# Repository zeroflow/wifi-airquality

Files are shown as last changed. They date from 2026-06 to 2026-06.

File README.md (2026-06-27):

# wifi-airquality

Air-quality monitor with a visual air-quality indicator, built with
[ESPHome](https://esphome.io/) and [Home Assistant](https://www.home-assistant.io/).
Companion project to a fan controller: when the basement air gets dirty, the
lightbar shows it and the fans throttle down or switch off.

*Sponsored by [Seeed Studio](https://www.seeedstudio.com/).*

## Devices

| Config | MCU | Hardware |
| --- | --- | --- |
| [`sensor.yaml`](sensor.yaml) | Seeed XIAO ESP32-C6 | Sensirion SEN55 (PM/VOC/NOx/T/RH) + SHT41, OLED, RTC, buzzer |
| [`ledbar.yaml`](ledbar.yaml) | Seeed XIAO ESP32-C3 | 10-LED WS2812 lightbar as an AQI gauge |

The **sensor** station measures particulate matter, VOC, NOx, temperature and
humidity and publishes them to Home Assistant. The **lightbar** subscribes to a
Home Assistant air-quality score and visualizes it (green = good, breathing red
= warning, blinking red = critical), with configurable thresholds and brightness.

## Package Library

This repository is an ESPHome **package library** — composable building blocks you import
directly into your own device config via `packages: github://`. No forking required.

All packages are tagged at `@v1.0.0`. Use this tag in production configs for stability.
See each layer's `README.md` for full documentation, exposed ids, and `!extend` examples.

### Hardware layer — [`packages/hardware/`](packages/hardware/)

| Package | One-liner | Import key |
|---|---|---|
| `xiao-esp32c3.yaml` | Seeed XIAO ESP32-C3 MCU + ESP-IDF framework | `mcu` |
| `xiao-esp32c6.yaml` | Seeed XIAO ESP32-C6 MCU + ESP-IDF framework | `mcu` |
| `grove-expansion-base.yaml` | XIAO Expansion Base — I2C, OLED, RTC, buzzer, button | `shield` |
| `grove-led-driver.yaml` | Grove LED Driver Board — 10-LED WS2812 strip on GPIO07 | `led_hw` |

### Sensors layer — [`packages/sensors/`](packages/sensors/)

| Package | One-liner | Import key |
|---|---|---|
| `sen55.yaml` | Sensirion SEN55 — PM1/2.5/4/10 + VOC + NOx + T/RH | `sensors_sen` |
| `sht41.yaml` | Sensirion SHT41 — temperature + humidity | `sensors_sht` |

### Display layer — [`packages/display/`](packages/display/)

| Package | One-liner | Import key |
|---|---|---|
| `oled-airquality.yaml` | Air-quality dashboard on the OLED (T/RH, PM, VOC/NOx, bar) | `oled_display` |

### AQI gauge layer — [`packages/aqi/`](packages/aqi/)

| Package | One-liner | Import key |
|---|---|---|
| `ledbar-gauge.yaml` | AQI Gauge effect on LED strip — 4-state visual from HA sensor | `aqi_gauge` |

---

### Copy-paste import snippets

**Sensor station** (XIAO C6 + Expansion Base + SEN55 + SHT41 + OLED):

```yaml
# Shorthand — no substitution overrides needed
packages:
  mcu:          github://zeroflow/wifi-airquality/packages/hardware/xiao-esp32c6.yaml@v1.0.0
  shield:       github://zeroflow/wifi-airquality/packages/hardware/grove-expansion-base.yaml@v1.0.0
  sensors_sen:  github://zeroflow/wifi-airquality/packages/sensors/sen55.yaml@v1.0.0
  sensors_sht:  github://zeroflow/wifi-airquality/packages/sensors/sht41.yaml@v1.0.0
  oled_display: github://zeroflow/wifi-airquality/packages/display/oled-airquality.yaml@v1.0.0
```

**LED bar gauge** (XIAO C3 + LED Driver + AQI Gauge):

```yaml
# Shorthand — uses default HA entity sensor.air_quality_score
packages:
  mcu:       github://zeroflow/wifi-airquality/packages/hardware/xiao-esp32c3.yaml@v1.0.0
  led_hw:    github://zeroflow/wifi-airquality/packages/hardware/grove-led-driver.yaml@v1.0.0
  aqi_gauge: github://zeroflow/wifi-airquality/packages/aqi/ledbar-gauge.yaml@v1.0.0
```

**LED bar gauge with custom HA entity** (long-form with `vars:`):

```yaml
# Long-form — override aqi_entity_id to match your Home Assistant entity name
packages:
  mcu:    github://zeroflow/wifi-airquality/packages/hardware/xiao-esp32c3.yaml@v1.0.0
  led_hw: github://zeroflow/wifi-airquality/packages/hardware/grove-led-driver.yaml@v1.0.0
  aqi_gauge:
    url: github://zeroflow/wifi-airquality/packages/aqi/ledbar-gauge.yaml@v1.0.0
    vars:
      aqi_entity_id: sensor.basement_air_quality
```

**Custom LED strip** (long-form overriding `led_count` and `led_pin`):

```yaml
packages:
  led_hw:
    url: github://zeroflow/wifi-airquality/packages/hardware/grove-led-driver.yaml@v1.0.0
    vars:
      led_count: "30"
      led_pin: GPIO04
```

**Custom SEN55 poll rate** (long-form overriding `sen55_update_interval`):

```yaml
packages:
  sensors_sen:
    url: github://zeroflow/wifi-airquality/packages/sensors/sen55.yaml@v1.0.0
    vars:
      sen55_update_interval: "10s"
```

---

## Enclosures

3D-printable mounts for both devices live in [`enclosure/`](enclosure/).

## Setup

Secrets are kept out of git. Create a `secrets.yaml` next to the configs:

```yaml
wifi_ssid: "your-ssid"
wifi_password: "your-password"
```

## Build

Validate and flash with ESPHome:

```bash
esphome config sensor.yaml
esphome run sensor.yaml
esphome run ledbar.yaml
```

## License

[MIT](LICENSE)

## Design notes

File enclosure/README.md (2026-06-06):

# Enclosures

Minimal 3D-printable mounts for the two devices. The goal is simply to keep the
PCBs from lying around loose and to hold the stack together. They are not meant to
be pretty or sturdy, just simple. Each `.3mf` is print-ready, and the `.png` next
to it is a render of the assembled result.

| Device | Model | Render |
| --- | --- | --- |
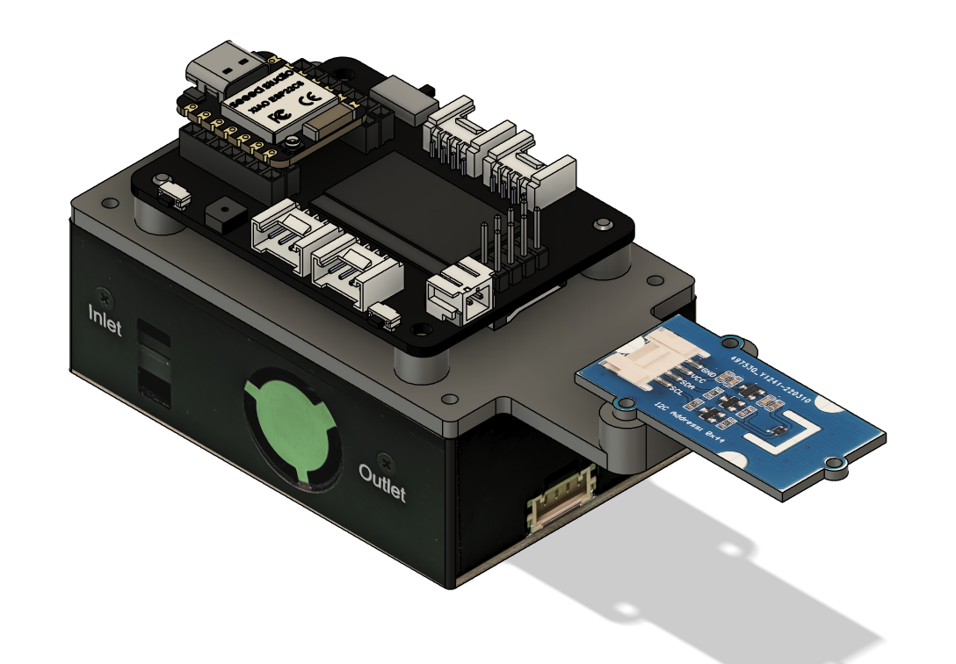
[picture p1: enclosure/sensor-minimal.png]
sensor
| [`sensor`](../sensor.yaml) | [`sensor-minimal.3mf`](sensor-minimal.3mf) |  |
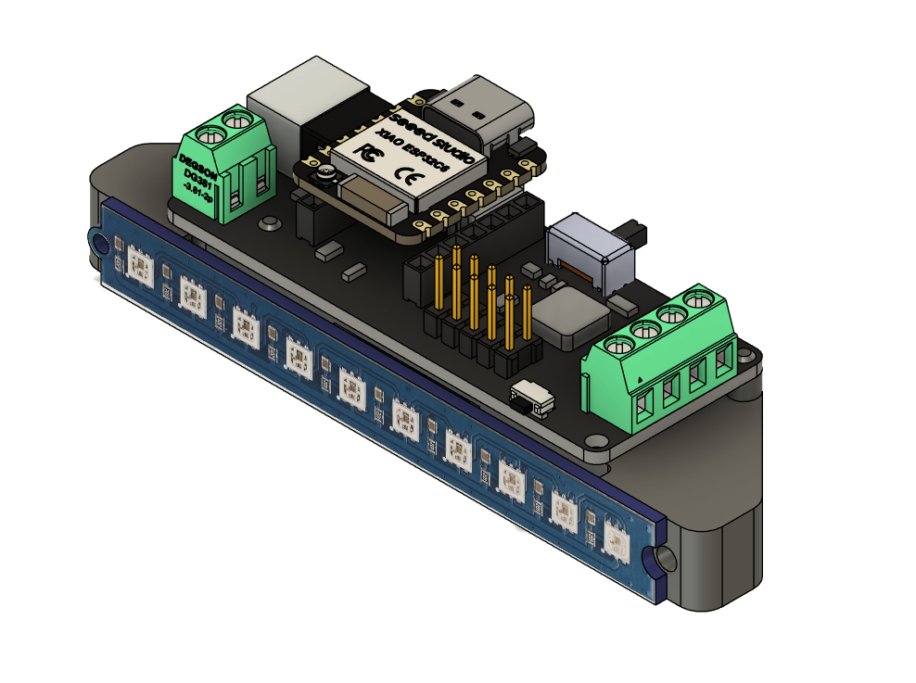
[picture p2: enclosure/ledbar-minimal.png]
ledbar
| [`ledbar`](../ledbar.yaml) | [`ledbar-minimal.3mf`](ledbar-minimal.3mf) |  |

## sensor

Replaces the SEN55's top plate: the printed part drops straight onto the sensor
in place of the stock cover. It carries the rest of the stack on top.

- **XIAO distribution board**, mounted with **M3** screws.
- **SHT41** breakout, mounted with **M2** screws.

## ledbar

A flat carrier for the lightbar and its XIAO.

- **LED strip**, glued and screwed down (**M3 + M2**).
- **XIAO board**, held by double-sided tape only, no screws.

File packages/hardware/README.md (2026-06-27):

# packages/hardware/

Hardware packages for the Seeed XIAO series and Grove peripherals. Each package
configures the MCU or a Grove board and exposes stable `id`s for composition.

---

## `xiao-esp32c3.yaml`

**What it configures:** Seeed XIAO ESP32-C3 MCU and ESP-IDF framework — nothing else.

**Hardware / package dependencies:**
- None (board-only package; no Grove peripherals)

**Exposed ids:**

*(No ids exposed — MCU and framework declaration only)*

**Substitutions:**

| name | value | purpose |
|---|---|---|
| `pin_a0` | `"2"` | A0 silkscreen → GPIO2 |
| `pin_d3` | `"5"` | D3 silkscreen → GPIO5 |
| `pin_d4` | `"6"` | D4 / SDA → GPIO6 |
| `pin_d5` | `"7"` | D5 / SCL → GPIO7 (== legacy MVP GPIO07) |

These substitutions are a **workaround** for missing XIAO C3 silkscreen aliases in ESPHome
2026.5.0 (pinned). ESPHome PR #17002 adds C3/S3 aliases but targets the unreleased 2026.6.0.
Feature packages (e.g. `grove-led-driver-i2c.yaml`) reference `${pin_a0}` / `${pin_d5}` /
`${pin_d3}` directly at point of use — no nested substitution-in-substitution indirection.

**Example override with `!extend`:**

The XIAO C3 package has no exposed ids, so `!extend` is not applicable.
Consumer adds device identity, networking, and peripherals in their own config.

**Import:**

```yaml
packages:
  mcu: github://zeroflow/wifi-airquality/packages/hardware/xiao-esp32c3.yaml@v1.0.0
  # local development:
  # mcu: !include packages/hardware/xiao-esp32c3.yaml
```

---

## `xiao-esp32c6.yaml`

**What it configures:** Seeed XIAO ESP32-C6 MCU and ESP-IDF framework — nothing else.

**Hardware / package dependencies:**
- None (board-only package; no Grove peripherals)

**Exposed ids:**

*(No ids exposed — MCU and framework declaration only)*

**Substitutions:**

| name | value | purpose |
|---|---|---|
| `pin_a0` | `"0"` | A0 silkscreen → GPIO0 |
| `pin_d3` | `"21"` | D3 silkscreen → GPIO21 |
| `pin_d4` | `"22"` | D4 / SDA → GPIO22 |
| `pin_d5` | `"23"` | D5 / SCL → GPIO23 |

See C3 note above — same workaround applies for the C6 pin-name substitutions.

**Example override with `!extend`:**

The XIAO C6 package has no exposed ids, so `!extend` is not applicable.
Consumer adds device identity, networking, and peripherals in their own config.

**Import:**

```yaml
packages:
  mcu: github://zeroflow/wifi-airquality/packages/hardware/xiao-esp32c6.yaml@v1.0.0
  # local development:
  # mcu: !include packages/hardware/xiao-esp32c6.yaml
```

---

## `grove-expansion-base.yaml`

**What it configures:** All onboard peripherals of the Seeed XIAO Expansion Base — I2C bus,
0.96" OLED (shows clock by default), PCF8563 RTC with SNTP write-back, passive buzzer,
and user button.

**Hardware / package dependencies:**
- Requires a XIAO board package (`xiao-esp32c3.yaml` or `xiao-esp32c6.yaml`) for the
  underlying MCU

**Exposed ids:**

| id | type | notes |
|----|---|---|
| `bus_a` | i2c | SDA=D4, SCL=D5 (overridable via substitutions); consumed by sensor and display packages |
| `oled` | display (ssd1306\_i2c 0x3C) | 128×64 OLED; default lambda shows clock; `!extend` target for custom display content |
| `roboto` | font (Roboto, size 14) | Referenced in display lambdas |
| `rtc_time` | time (pcf8563 0x51) | Hardware RTC; SNTP writes back to it on sync |
| `sntp_time` | time (sntp) | SNTP source; writes to `rtc_time` on sync |
| `user_button` | binary\_sensor (gpio D1, pullup, inverted) | Bare GPIO — no automations in package |
| `buzzer_out` | output (ledc D3) | LEDC PWM output driving the buzzer |
| `buzzer` | rtttl | RTTTL player; play tones via `rtttl.play` |

**Substitutions:**

| name | default | purpose |
|---|---|---|
| `i2c_sda` | `D4` | I2C SDA pin |
| `i2c_scl` | `D5` | I2C SCL pin |

**Example override with `!extend`:**

```yaml
# Change the OLED content without forking the package
display:
  - id: !extend oled
    lambda: |-
      it.printf(0, 0, id(roboto), "PM2.5: %.0f", id(sen_pm25).state);
```

**Import:**

```yaml
packages:
  shield: github://zeroflow/wifi-airquality/packages/hardware/grove-expansion-base.yaml@v1.0.0
  # local development:
  # shield: !include packages/hardware/grove-expansion-base.yaml
```

---

## `grove-led-driver-i2c.yaml`

**What it configures:** Seeed LED Driver Board for XIAO — **I2C variant**.

- `aqi_strip` — WS2812 addressable LED strip on the terminal-block LED connector (A0 / `${pin_a0}`)
- `driver_button` — user button on D3 / `${pin_d3}` (INPUT_PULLUP, inverted, no automations)

The Grove I2C connector is **left free** for the consumer. Pair with `grove-expansion-base.yaml`
or add your own `i2c:` block to use I2C sensors/OLED on that connector.

Consumers add effects via `!extend aqi_strip`. See `packages/aqi/ledbar-gauge.yaml` for an
AQI gauge effect that extends this strip.

**Hardware / package dependencies:**
- Requires a XIAO board package (`xiao-esp32c3.yaml` or `xiao-esp32c6.yaml`) — the board
  package exports `pin_a0` and `pin_d3` consumed here

**Exposed ids:**

| id | type | notes |
|----|---|---|
| `aqi_strip` | light (esp32\_rmt\_led\_strip) | 10 LEDs, WS2812, GRB order; `!extend` target for effect packages |
| `driver_button` | binary\_sensor (gpio INPUT\_PULLUP inverted) | Bare GPIO on D3 — no automations in package |

**Substitutions:**

| name | default | purpose |
|---|---|---|
| `led_count` | `"10"` | Number of LEDs in the strip |

Pins (`pin_a0`, `pin_d3`) are exported by the board package — override them at the board level,
not here. Do not nest `${pin_a0}` inside another substitution value.

**Pin map:**

| Silkscreen | C3 GPIO | C6 GPIO | Connected to |
|---|---|---|---|
| A0 | GPIO2 | GPIO0 | Terminal-block LED strip data (`aqi_strip`) |
| D3 | GPIO5 | GPIO21 | User button (`driver_button`) |

Note: The GPIO numbers are provided by the board package substitutions as a workaround for
missing C3 silkscreen aliases in ESPHome 2026.5.0 (PR #17002 not yet released).

**Example override with `!extend`:**

```yaml
# Add a Rainbow effect to the strip without forking the package
light:
  - id: !extend aqi_strip
    effects:
      - random:
          name: "Twinkle"
          transition_length: 600ms
          update_interval: 300ms
```

**Import:**

```yaml
packages:
  mcu:    github://zeroflow/wifi-airquality/packages/hardware/xiao-esp32c3.yaml@v1.0.0
  led_hw: github://zeroflow/wifi-airquality/packages/hardware/grove-led-driver-i2c.yaml@v1.0.0
  # local development:
  # led_hw: !include packages/hardware/grove-led-driver-i2c.yaml
```

---

## `grove-led-driver-neopixel.yaml`

**What it configures:** Seeed LED Driver Board for XIAO — **Neopixel variant**.

- `aqi_strip` — WS2812 addressable LED strip on the terminal-block LED connector (A0 / `${pin_a0}`)
- `grove_strip` — second WS2812 strip on the Grove I2C connector repurposed as D5 / `${pin_d5}` data output
- `driver_button` — user button on D3 / `${pin_d3}` (INPUT_PULLUP, inverted, no automations)

The Grove I2C connector is **repurposed** as a neopixel data line in this variant.
The Grove connector is **NOT available for I2C** here. Use the I2C variant
(`grove-led-driver-i2c.yaml`) if you need I2C sensors/OLED on the Grove connector.

**Hardware / package dependencies:**
- Requires a XIAO board package (`xiao-esp32c3.yaml` or `xiao-esp32c6.yaml`) — the board
  package exports `pin_a0`, `pin_d3`, and `pin_d5` consumed here

**Exposed ids:**

| id | type | notes |
|----|---|---|
| `aqi_strip` | light (esp32\_rmt\_led\_strip) | 10 LEDs, WS2812, GRB order; terminal-block strip on A0; `!extend` target for effect packages |
| `grove_strip` | light (esp32\_rmt\_led\_strip) | 10 LEDs, WS2812, GRB order; Grove-connector strip on D5 |
| `driver_button` | binary\_sensor (gpio INPUT\_PULLUP inverted) | Bare GPIO on D3 — no automations in package |

**Substitutions:**

| name | default | purpose |
|---|---|---|
| `led_count` | `"10"` | Number of LEDs per strip (applies to both `aqi_strip` and `grove_strip`) |

Pins (`pin_a0`, `pin_d3`, `pin_d5`) are exported by the board package — override them at the
board level. Do not nest `${pin_*}` inside another substitution value.

**Pin map:**

| Silkscreen | C3 GPIO | C6 GPIO | Connected to |
|---|---|---|---|
| A0 | GPIO2 | GPIO0 | Terminal-block LED strip data (`aqi_strip`) |
| D5 | GPIO7 | GPIO23 | Grove-connector LED strip data (`grove_strip`); note D5/GPIO7 == legacy MVP GPIO07 |
| D3 | GPIO5 | GPIO21 | User button (`driver_button`) |

Note: The GPIO numbers are provided by the board package substitutions as a workaround for
missing C3 silkscreen aliases in ESPHome 2026.5.0 (PR #17002 not yet released).

**Variant sibling note:** `aqi_strip` and `driver_button` are intentionally shared with
`grove-led-driver-i2c.yaml`. These two packages are mutually exclusive — a consumer imports
exactly one. Guard 2 in `test-examples.sh` recognizes this as a valid sibling pair.

**Example override with `!extend`:**

```yaml
# Add a solid color effect to the Grove-connector strip
light:
  - id: !extend grove_strip
    effects:
      - random:
          name: "Twinkle"
          transition_length: 600ms
          update_interval: 300ms
```

**Import:**

```yaml
packages:
  mcu:    github://zeroflow/wifi-airquality/packages/hardware/xiao-esp32c3.yaml@v1.0.0
  led_hw: github://zeroflow/wifi-airquality/packages/hardware/grove-led-driver-neopixel.yaml@v1.0.0
  # local development:
  # led_hw: !include packages/hardware/grove-led-driver-neopixel.yaml
```

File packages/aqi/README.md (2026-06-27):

# packages/aqi/

AQI gauge packages that drive the LED strip as a visual air-quality indicator.
Each package `!extend`s the hardware-owned `aqi_strip` light entity declared
by `grove-led-driver.yaml`.

---

## `ledbar-gauge.yaml`

**What it configures:** AQI Gauge code package — adds the "AQI Gauge" `addressable_lambda`
effect to the `aqi_strip` light, subscribes to a Home Assistant air-quality score entity,
and exposes 5 HA-configurable number entities for thresholds and brightness.

The gauge has four visual states:

| Score range | State | Visual |
|---|---|---|
| < threshold\_green | Very good | 2 green LEDs at center |
| threshold\_green – threshold\_warn | Normal | Gauge expands center-out, green→yellow→red |
| threshold\_warn – threshold\_critical | Warning | All red, sine breathing |
| ≥ threshold\_critical | Critical | All red, hard 5 Hz blink |

Decorative effects (Rainbow, Scan, etc.) are intentionally **not included** in this
package. A consumer who wants them adds their own `!extend aqi_strip` with additional
effects (D-25).

**Hardware / package dependencies:**
- `grove-led-driver.yaml` — provides `aqi_strip` (the `!extend` target)
- Requires a XIAO board package for the underlying MCU

> **Note:** This package validates only in composition (e.g. `examples/ledbar.yaml`).
> Do not add it to `examples/` for standalone validation — `aqi_strip` is declared by
> `grove-led-driver.yaml` and does not exist in isolation.

**Exposed ids:**

| id | type | notes |
|----|---|---|
| `air_quality` | sensor (homeassistant) | Subscribes to the HA entity set by `aqi_entity_id`; drives the gauge lambda |
| `threshold_green` | number (template) | Lower AQI threshold; initial 5 (range 1–30) |
| `threshold_warn` | number (template) | Warning AQI threshold; initial 85 (range 50–100) |
| `threshold_critical` | number (template) | Critical AQI threshold; initial 95 (range 80–100) |
| `brightness` | number (template, %) | Overall LED brightness cap; initial 10% |
| `breath` | number (template, %) | Breath depth for warning sine animation; initial 80% |

**Substitutions:**

| name | default | purpose |
|---|---|---|
| `aqi_entity_id` | `sensor.air_quality_score` | Which Home Assistant entity feeds the gauge; override to match your HA entity name |

**Example override with `!extend`:**

**Option A — Simple: change the HA entity via substitution** (most consumers):

```yaml
packages:
  aqi_gauge:
    url: github://zeroflow/wifi-airquality/packages/aqi/ledbar-gauge.yaml@v1.0.0
    vars:
      aqi_entity_id: sensor.basement_air_quality
```

**Option B — Power user: override the sensor entity with `!extend`** (D-27):

Use `!extend air_quality` when you need to change more than the `entity_id` —
for example, to add `filters:`, set a custom `name:`, or bind a different platform:

```yaml
sensor:
  - id: !extend air_quality
    entity_id: sensor.my_custom_aqi
    filters:
      - sliding_window_moving_average:
          window_size: 5
          send_every: 1
```

**Adding decorative effects** (D-25): The package ships only the AQI Gauge effect.
To add Rainbow, Scan, or other effects without forking, extend the strip:

```yaml
light:
  - id: !extend aqi_strip
    effects:
      - addressable_rainbow:
          name: "Rainbow"
          speed: 10
          width: 50
```

**Import:**

```yaml
packages:
  aqi_gauge: github://zeroflow/wifi-airquality/packages/aqi/ledbar-gauge.yaml@v1.0.0
  # local development:
  # aqi_gauge: !include packages/aqi/ledbar-gauge.yaml
```

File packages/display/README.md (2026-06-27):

# packages/display/

Display packages that render sensor data onto the OLED screen. Each package
`!extend`s the hardware-owned `oled` display entity declared by
`grove-expansion-base.yaml`.

---

## `oled-airquality.yaml`

**What it configures:** Air-quality display lambda — overrides the default clock display
on the OLED with a 4-row air-quality dashboard (temperature/humidity, PM2.5/PM10,
VOC/NOx, VOC bar graph).

**Hardware / package dependencies:**
- `grove-expansion-base.yaml` — provides `oled` (display entity) and `roboto` (font)
- `sen55.yaml` — provides `sen_pm25`, `sen_pm10`, `sen_voc`, `sen_nox`
- `sht41.yaml` — provides `sht_temp`, `sht_hum`

> **Note:** This package validates only in composition (e.g. `examples/sensor-station.yaml`).
> Do not add it to `examples/` for standalone validation — the cross-package ids above
> do not exist in isolation and `esphome config` will fail with unknown-id errors.

**Exposed ids:**

*(No new ids declared — this package only `!extend`s the hardware-owned `oled` entity)*

**Substitutions:**

*(No substitutions)*

**Example override with `!extend`:**

```yaml
# Replace the air-quality dashboard with a custom one-line display
display:
  - id: !extend oled
    lambda: |-
      it.printf(0, 0, id(roboto), "VOC: %.0f", id(sen_voc).state);
```

**Import:**

```yaml
packages:
  oled_display: github://zeroflow/wifi-airquality/packages/display/oled-airquality.yaml@v1.0.0
  # local development:
  # oled_display: !include packages/display/oled-airquality.yaml
```

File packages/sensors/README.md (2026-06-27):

# packages/sensors/

Sensor packages for Grove air-quality modules. Each package wires a sensor to
the `bus_a` I2C bus (owned by `grove-expansion-base.yaml`) and exposes stable
`id`s for display and automation packages.

---

## `sen55.yaml`

**What it configures:** Sensirion SEN55 particulate + gas sensor — PM1.0, PM2.5, PM4.0,
PM10, VOC index, NOx index, temperature, and humidity over I2C.

**Hardware / package dependencies:**
- `grove-expansion-base.yaml` — provides `bus_a` (I2C bus at D4/D5)

**Exposed ids:**

| id | type | notes |
|----|---|---|
| `sen55` | sensor (sen5x) | SEN55 parent sensor; used for autoclean trigger |
| `sen_pm25` | sensor sub-id (pm\_2\_5) | PM2.5 weight concentration; consumed by `oled-airquality.yaml` |
| `sen_pm10` | sensor sub-id (pm\_10\_0) | PM10 weight concentration; consumed by `oled-airquality.yaml` |
| `sen_voc` | sensor sub-id (voc) | VOC index; consumed by `oled-airquality.yaml` |
| `sen_nox` | sensor sub-id (nox) | NOx index; consumed by `oled-airquality.yaml` |

**Substitutions:**

| name | default | purpose |
|---|---|---|
| `sen55_update_interval` | `"60s"` | How often the sensor reads; reduce for faster dashboard updates |

**Example override with `!extend`:**

```yaml
# Speed up SEN55 readings for a responsive dashboard
sensor:
  - id: !extend sen55
    update_interval: 10s
```

**Import:**

```yaml
packages:
  sensors_sen: github://zeroflow/wifi-airquality/packages/sensors/sen55.yaml@v1.0.0
  # local development:
  # sensors_sen: !include packages/sensors/sen55.yaml
```

---

## `sht41.yaml`

**What it configures:** Sensirion SHT41 temperature and humidity sensor over I2C.

**Hardware / package dependencies:**
- `grove-expansion-base.yaml` — provides `bus_a` (I2C bus at D4/D5)

**Exposed ids:**

| id | type | notes |
|----|---|---|
| `sht_temp` | sensor (sht4x temperature) | Temperature reading; consumed by `oled-airquality.yaml` |
| `sht_hum` | sensor (sht4x humidity) | Humidity reading; consumed by `oled-airquality.yaml` |

**Substitutions:**

| name | default | purpose |
|---|---|---|
| `sht41_update_interval` | `"60s"` | How often the sensor reads; reduce for faster dashboard updates |

**Example override with `!extend`:**

```yaml
# Speed up SHT41 readings to 10s without forking the package
sensor:
  - id: !extend sht_temp
    update_interval: 10s
```

**Import:**

```yaml
packages:
  sensors_sht: github://zeroflow/wifi-airquality/packages/sensors/sht41.yaml@v1.0.0
  # local development:
  # sensors_sht: !include packages/sensors/sht41.yaml
```

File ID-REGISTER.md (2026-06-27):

# ID-REGISTER.md — ESPHome Shared ID Ownership

This register maps every shared ESPHome `id` to exactly one owning package file (or a
declared variant-sibling pair — see Variant-Suffix Convention below).
No `id` may be declared in more than one package file (enforced by `test-examples.sh`),
unless the files are recognized variant siblings differing only by a `-i2c` / `-neopixel` suffix.
Consumers reference ids across packages using `!extend <id>`.

**Owning package** = the package file that declares the `id:` in its YAML.
**Consumers** = packages or example configs that reference (but do not declare) the id.

The no-duplicate-id contract is enforced automatically by the duplicate-`id` check in
`test-examples.sh`. Any id declared in more than one package file causes the check to
fail before `esphome config` runs (with the variant-sibling exemption; see below).

---

## From `sensor.yaml` (hardware + sensor + display ids)

| id | type | owning package file | consumers | notes |
|----|---|---|---|---|
| `bus_a` | i2c | `packages/hardware/grove-expansion-base.yaml` | sen55, sht41, oled, rtc_time | SDA=D4, SCL=D5 |
| `oled` | display (ssd1306_i2c 0x3C) | `packages/hardware/grove-expansion-base.yaml` | oled-airquality.yaml | `!extend` target for display lambda |
| `roboto` | font (Roboto, size 14) | `packages/hardware/grove-expansion-base.yaml` | oled-airquality.yaml | referenced in display lambda |
| `rtc_time` | time (pcf8563 0x51) | `packages/hardware/grove-expansion-base.yaml` | — | write-back target for sntp_time |
| `sntp_time` | time (sntp) | `packages/hardware/grove-expansion-base.yaml` | — | writes to rtc_time on_time_sync |
| `user_button` | binary_sensor (gpio D1, pullup, inverted) | `packages/hardware/grove-expansion-base.yaml` | — | triggers fan autoclean + buzzer |
| `buzzer_out` | output (ledc D3) | `packages/hardware/grove-expansion-base.yaml` | buzzer | ledc PWM output |
| `buzzer` | rtttl | `packages/hardware/grove-expansion-base.yaml` | — | driven by buzzer_out |
| `sen55` | sensor (sen5x) | `packages/sensors/sen55.yaml` | user_button (autoclean) | SEN55 parent sensor |
| `sen_pm25` | sensor sub-id (pm_2_5) | `packages/sensors/sen55.yaml` | oled-airquality.yaml | child of sen55 |
| `sen_pm10` | sensor sub-id (pm_10_0) | `packages/sensors/sen55.yaml` | oled-airquality.yaml | child of sen55 |
| `sen_voc` | sensor sub-id (voc) | `packages/sensors/sen55.yaml` | oled-airquality.yaml | child of sen55 |
| `sen_nox` | sensor sub-id (nox) | `packages/sensors/sen55.yaml` | oled-airquality.yaml | child of sen55 |
| `sht_temp` | sensor (sht4x temperature) | `packages/sensors/sht41.yaml` | oled-airquality.yaml | |
| `sht_hum` | sensor (sht4x humidity) | `packages/sensors/sht41.yaml` | oled-airquality.yaml | |

## From `ledbar.yaml` (AQI gauge + light ids)

| id | type | owning package file | consumers | notes |
|----|---|---|---|---|
| `aqi_strip` | light (esp32_rmt_led_strip A0/${pin_a0}) | `grove-led-driver-i2c.yaml` / `grove-led-driver-neopixel.yaml` | ledbar-gauge.yaml | variant-pair; shared by design, never composed together — see Variant-Suffix Convention |
| `grove_strip` | light (esp32_rmt_led_strip D5/${pin_d5}) | `packages/hardware/grove-led-driver-neopixel.yaml` | — | neopixel variant only; Grove I2C connector repurposed as second strip data output |
| `driver_button` | binary_sensor (gpio ${pin_d3} INPUT_PULLUP inverted) | `grove-led-driver-i2c.yaml` / `grove-led-driver-neopixel.yaml` | — | variant-pair; D3 reuse across boards is acceptable (different physical hardware from user_button/buzzer_out) |
| `air_quality` | sensor (homeassistant entity) | `packages/aqi/ledbar-gauge.yaml` | addressable_lambda | HA entity: sensor.air_quality_score |
| `threshold_green` | number (template) | `packages/aqi/ledbar-gauge.yaml` | addressable_lambda | AQI gauge lower threshold |
| `threshold_warn` | number (template) | `packages/aqi/ledbar-gauge.yaml` | addressable_lambda | AQI gauge warning threshold |
| `threshold_critical` | number (template) | `packages/aqi/ledbar-gauge.yaml` | addressable_lambda | AQI gauge critical threshold |
| `brightness` | number (template, %) | `packages/aqi/ledbar-gauge.yaml` | addressable_lambda | overall brightness cap; initial 10% |
| `breath` | number (template, %) | `packages/aqi/ledbar-gauge.yaml` | addressable_lambda | breath depth for warning state; initial 80% |

---

## Variant-Suffix Convention

Package files that differ **only** by a trailing variant suffix (`-i2c` or `-neopixel`)
before the `.yaml` extension are **sibling packages**. A consumer imports exactly one of them;
the two variants are mutually exclusive and must never be composed together.

Examples:
- `packages/hardware/grove-led-driver-i2c.yaml` — terminal strip + button; Grove I2C connector left free
- `packages/hardware/grove-led-driver-neopixel.yaml` — terminal strip + Grove strip + button; Grove connector repurposed

Sibling packages intentionally share ids (`aqi_strip`, `driver_button`). This is valid by design
and is NOT a duplicate-id violation. `test-examples.sh` Guard 2 strips the `-i2c` / `-neopixel`
variant suffix before deduplication, so both siblings map to the same canonical stem
(`grove-led-driver`) and are counted once — not flagged.

A genuine id collision in **unrelated** package files (files with different non-variant-suffixed
basenames) still maps to two distinct canonical stems and is correctly reported by Guard 2.

---

## Cross-Check Notes

All ids were verified against the frozen MVP YAMLs (`sensor.yaml` and `ledbar.yaml`) at initial
seeding (2026-06-07) and updated for the LED Driver Board variant refactor (2026-06-27).

Sub-ids (`sen_pm25`, `sen_pm10`, `sen_voc`, `sen_nox`) carry their own `id:` declarations
within the `sen5x` platform block in `sensor.yaml`, making them independently referenceable
via `!extend`.

`driver_button` (D3, LED Driver Board) is distinct from `user_button` (D1, Expansion Base) and
`buzzer_out` (D3 LEDC, Expansion Base). The D3 reuse across different physical boards is
intentional; consumers never compose the Expansion Base and the LED Driver Board together.

---

## Enforcement

The duplicate-id check in `test-examples.sh` scans all `packages/**/*.yaml` files at
validation time. If any `id:` value appears in more than one package file (after variant-sibling
normalization), the script exits non-zero before running `esphome config`. The register is the
written contract; the script is its automated enforcement.

---

*Seeded: 2026-06-07 from sensor.yaml (15 ids) and ledbar.yaml (7 ids)*
*Last updated: 2026-06-27 — Quick task 260627-qc8: LED Driver Board variant refactor (D1–D6)*

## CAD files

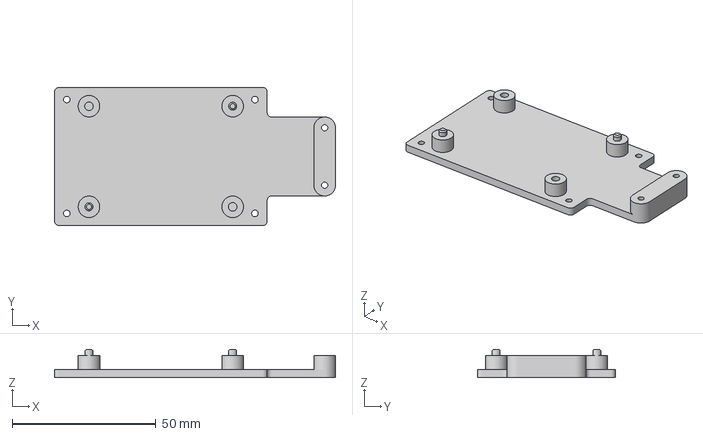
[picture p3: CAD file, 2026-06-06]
enclosure/sensor-minimal.3mf
97.8 x 48.0 x 9.90 mm

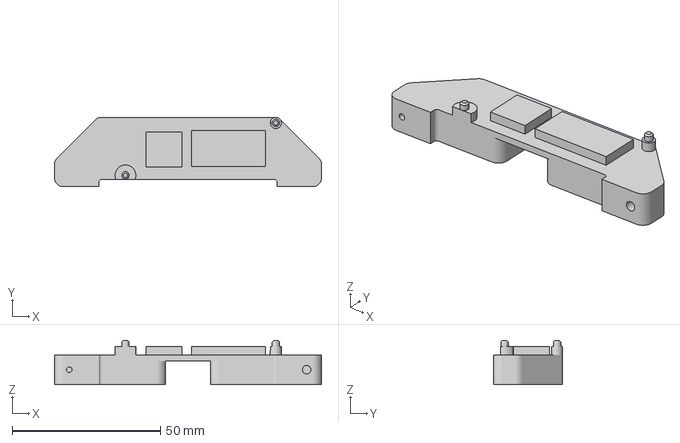
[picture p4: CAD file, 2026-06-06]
enclosure/ledbar-minimal.3mf
90.0 x 23.4 x 14.9 mm

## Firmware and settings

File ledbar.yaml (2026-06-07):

esphome:
  name: seeed-ledbar
  friendly_name: seeed-ledbar
  on_boot:
    priority: -100
    then:
      - light.turn_on:
          id: aqi_strip
          effect: "AQI Gauge"

# https://www.seeedstudio.com/LED-Driver-Board-for-Seeed-Studio-XIAO-p-6451.html
# https://wiki.seeedstudio.com/led_driver_board/

esp32:
  board: seeed_xiao_esp32c3
  framework:
    type: esp-idf

# Enable logging
logger:

# Enable Home Assistant API
api:
  encryption:
    # DUMMY key - replace before flashing! Generate your own with:
    #   openssl rand -base64 32
    # (must be valid base64 of 32 bytes; this placeholder decodes to
    #  "esphome_dummy_key_replace_me_!!!")
    key: "ZXNwaG9tZV9kdW1teV9rZXlfcmVwbGFjZV9tZV8hISE="

ota:
  - platform: esphome
    # DUMMY - replace before flashing (any string).
    password: "changeme"

wifi:
  ssid: !secret wifi_ssid
  password: !secret wifi_password

  # Enable fallback hotspot (captive portal) in case wifi connection fails
  ap:
    ssid: "Seeed-Ledbar Fallback Hotspot"
    # DUMMY - replace before flashing (8–63 chars).
    password: "changeme"

  use_address: 192.168.5.182
  
captive_portal:

sensor:
  - platform: homeassistant
    id: air_quality
    entity_id: sensor.air_quality_score   # your HA entity

number:
  - platform: template
    name: "AQI Threshold Green"
    id: threshold_green
    mode: box
    min_value: 1
    max_value: 30
    step: 1
    initial_value: 5
    restore_value: true
    optimistic: true
    entity_category: config

  - platform: template
    name: "AQI Threshold Warning"
    id: threshold_warn
    mode: box
    min_value: 50
    max_value: 100
    step: 1
    initial_value: 85
    restore_value: true
    optimistic: true
    entity_category: config

  - platform: template
    name: "AQI Threshold Critical"
    id: threshold_critical
    mode: box
    min_value: 80
    max_value: 100
    step: 1
    initial_value: 95
    restore_value: true
    optimistic: true
    entity_category: config

  - platform: template
    name: "Brightness"
    id: brightness
    mode: box
    min_value: 0
    max_value: 100
    step: 1
    initial_value: 10
    restore_value: true
    optimistic: true
    unit_of_measurement: "%"
    entity_category: config

  - platform: template
    name: "Breath Depth"
    id: breath
    mode: box
    min_value: 0
    max_value: 100
    step: 1
    initial_value: 80
    restore_value: true
    optimistic: true
    unit_of_measurement: "%"
    entity_category: config

light:
  - platform: esp32_rmt_led_strip
    name: "Grove RGB LED Stick"
    id: aqi_strip
    pin: GPIO07
    num_leds: 10
    chipset: WS2812          # WS2813 = WS2812-Timing
    rgb_order: GRB
    gamma_correct: 1.0 # so 1% color in homeassistant works as well.
    default_transition_length: 0s
    effects:
      # Status effects: Home Assistant sets the color, the effect provides the
      # motion or meaning. "Solid" needs no effect (just set the color).
      - pulse:
          name: "Breathe"          # calm / ok / info, soft breathing
          transition_length: 1s
          update_interval: 1s
      - pulse:
          name: "Blink"            # attention / warning, hard on/off ~1 Hz
          transition_length: 0s
          update_interval: 500ms
      - pulse:
          name: "Blink Fast"       # urgent / error / alarm
          transition_length: 0s
          update_interval: 200ms
      - addressable_scan:
          name: "Scan"             # activity / busy / running
          move_interval: 80ms
          scan_width: 1
      - addressable_flicker:
          name: "Flicker"          # live / unstable signal
          update_interval: 16ms
          intensity: 5%
      - addressable_rainbow:
          name: "Rainbow"          # celebrate / neutral idle
          speed: 10
          width: 50
      - addressable_rainbow:
          name: "Rainbow Slow"     # gentle idle
          speed: 3
          width: 10
      - addressable_lambda:
          name: "AQI Gauge"
          update_interval: 50ms
          lambda: |-
            // ── Guard: invalid config (div-by-zero) ──────────────────────
            float tw = id(threshold_warn).state;
            float tg = id(threshold_green).state;
            float tc = id(threshold_critical).state;
            float bright = id(brightness).state / 100.0f;
            float depth = id(breath).state / 100.0f;
            float bfloor = bright * (1.0f - depth);  // breath floor

            if (tw <= tg) {
              // degenerate config: all off
              for (int i = 0; i < it.size(); i++) it[i] = Color(0, 0, 0);
              return;
            }

            // ── Guard: no data from HA ───────────────────────────────────
            if (!id(air_quality).has_state() || isnan(id(air_quality).state)) {
              for (int i = 0; i < it.size(); i++) it[i] = Color(0, 0, 0);
              return;
            }

            float v = id(air_quality).state;
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

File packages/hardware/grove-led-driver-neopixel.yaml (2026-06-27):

# packages/hardware/grove-led-driver-neopixel.yaml
#
# Seeed LED Driver Board for XIAO — Neopixel variant
#
# What this configures:
#   aqi_strip     — WS2812 addressable LED strip on the terminal-block LED connector (A0)
#   grove_strip   — second WS2812 strip on the Grove I2C connector repurposed as D5 data output
#   driver_button — user button on D3 (INPUT_PULLUP, inverted, no automations)
#
# Grove I2C connector: REPURPOSED as a neopixel data output on D5.
# The Grove connector is NOT available for I2C sensors/OLED in this variant.
# Use the I2C variant (grove-led-driver-i2c.yaml) if you need the Grove connector for I2C.
#
# Requirements:
#   - A XIAO board package (xiao-esp32c3.yaml or xiao-esp32c6.yaml) MUST be imported
#     first; it exports the pin_a0, pin_d3, and pin_d5 substitutions consumed here.
#
# Note: aqi_strip and driver_button intentionally share ids with grove-led-driver-i2c.yaml.
# These two packages are MUTUALLY EXCLUSIVE — a consumer imports exactly one. The variant
# suffix (-i2c / -neopixel) is recognized by test-examples.sh Guard 2 as a sibling pair,
# so the shared ids do not trigger the duplicate-id check.
#
# No effects, no networking, no secrets in this file.
# Consumers add effects via !extend aqi_strip or !extend grove_strip.
#
# Import:
#   packages:
#     mcu:    github://zeroflow/wifi-airquality/packages/hardware/xiao-esp32c3.yaml@v1.0.0
#     led_hw: github://zeroflow/wifi-airquality/packages/hardware/grove-led-driver-neopixel.yaml@v1.0.0
#   # or for local development:
#   # led_hw: !include packages/hardware/grove-led-driver-neopixel.yaml

substitutions:
  led_count_grove: "10"   # number of LEDs per strip; string form for ESPHome integer coercion
  led_count_strip: "10"   # number of LEDs per strip; string form for ESPHome integer coercion

light:
  - platform: esp32_rmt_led_strip
    name: "Grove RGB LED Stick"
    id: aqi_strip
    pin: ${pin_a0}
    num_leds: ${led_count_grove}
    chipset: WS2812
    rgb_order: GRB
    gamma_correct: 1.0
    default_transition_length: 0s

  - platform: esp32_rmt_led_strip
    name: "Grove Connector LED Strip"
    id: grove_strip
    pin: ${pin_d5}
    num_leds: ${led_count_strip}
    chipset: WS2812
    rgb_order: GRB
    gamma_correct: 1.0
    default_transition_length: 0s

binary_sensor:
  - platform: gpio
    name: "Driver Button"
    id: driver_button
    pin:
      number: ${pin_d3}
      mode: INPUT_PULLUP
      inverted: true

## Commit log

2026-06-06 Initial commit, MVP
    [ledbar-minimal.3mf, sensor-minimal.3mf]
2026-06-07 update led bar, translate
2026-06-27 feat: composable ESPHome package library for XIAO + Grove air-quality hardware
    Reusable github://-importable ESPHome packages for Seeed XIAO + Grove
    air-quality hardware, refactored from the original sensor.yaml + ledbar.yaml
    MVP into composable building blocks.
    Packages:
    - hardware/ — XIAO ESP32-C3/C6 board configs, Grove Expansion Base,
    Grove LED Driver (i2c + neopixel variants) with pin_* substitution maps
    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
